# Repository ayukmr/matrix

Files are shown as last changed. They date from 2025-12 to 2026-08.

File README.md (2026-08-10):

# matrix



Charlieplexed LED matrix controlled by an ESP32-C6-MINI-1U.

## Schematic



## PCB



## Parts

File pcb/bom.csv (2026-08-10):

Reference | Qty | Value | Footprint | Datasheet | LCSC Part # | Link
C1,C2 | 2 | 2.2 µF | Capacitor_SMD:C_0603_1608Metric | ~ | C23630 | https://jlcpcb.com/partdetail/24366-CL10A225KO8NNNC/C23630
C3 | 1 | 1 µF | Capacitor_SMD:C_0603_1608Metric | ~ | C15849 | https://jlcpcb.com/partdetail/16531-CL10A105KB8NNNC/C15849
C4 | 1 | 22 µF | Capacitor_SMD:C_0603_1608Metric | ~ | C59461 | https://jlcpcb.com/partdetail/60514-CL10A226MQ8NRNC/C59461
C5 | 1 | 0.1 µF | Capacitor_SMD:C_0603_1608Metric | ~ | C14663 | https://jlcpcb.com/partdetail/YAGEO-CC0603KRX7R9BB104/C14663
D1,D2,D3,D4,D5,D6,D7,D8,D9,D10,D11,D12,D13,D14,D15,D16,D17,D18,D19,D20,D21,D22,D23,D24,D25,D26,D27,D28,D29,D30,D31,D32 | 32 | LED_Small | LED_SMD:LED_0603_1608Metric | ~ | C2286 | https://jlcpcb.com/partdetail/Hubei_KENTOElec-KT0603R/C2286
J1 | 1 | Conn_01x02 | Connector_JST:JST_PH_B2B-PH-SM4-TB_1x02-1MP_P2.00mm_Vertical | ~ | C160352 | https://jlcpcb.com/partdetail/JST-B2B_PH_SM4_TB_LF_SN/C160352
J2 | 1 | USB_C_Receptacle_USB2.0_14P | Connector_USB:USB_C_Receptacle_HRO_TYPE-C-31-M-12 | https://www.usb.org/sites/default/files/documents/usb_type-c.zip | C165948 | https://jlcpcb.com/partdetail/Korean_HropartsElec-TYPE_C_31_M12/C165948
R1,R2 | 2 | 5.1k Ω | Resistor_SMD:R_0603_1608Metric | ~ | C23186 | https://jlcpcb.com/partdetail/23913-0603WAF5101T5E/C23186
R3,R4 | 2 | 10k Ω | Resistor_SMD:R_0603_1608Metric | ~ | C25804 | https://jlcpcb.com/partdetail/26547-0603WAF1002T5E/C25804
R5,R6,R7,R8,R9,R10,R13,R14 | 8 | 470 Ω | Resistor_SMD:R_0603_1608Metric | ~ | C23179 | https://jlcpcb.com/partdetail/23906-0603WAF4700T5E/C23179
R11,R12 | 2 | 22 Ω | Resistor_SMD:R_0603_1608Metric | ~ | C23345 | https://jlcpcb.com/partdetail/24078-0603WAF220JT5E/C23345
SW1,SW2,SW3,SW4 | 4 | SW_Push | Button_Switch_SMD:SW_SPST_PTS810 | ~ | C720477 | https://jlcpcb.com/partdetail/XUNPU-TS_1088AR02016/C720477
U1 | 1 | ESP32-C6-MINI-1U | RF_Module:ESP32-C6-MINI-1U | https://www.espressif.com/sites/default/files/documentation/esp32-c6-mini-1_datasheet_en.pdf | C20627095 | https://jlcpcb.com/partdetail/22039339-ESP32_C6_MINI_1UH4/C20627095
U2 | 1 | XC6206PxxxMR | Package_TO_SOT_SMD:SOT-23-3 | https://www.torexsemi.com/file/xc6206/XC6206.pdf | C5446 | https://jlcpcb.com/partdetail/TorexSemicon-XC6206P332MRG/C5446

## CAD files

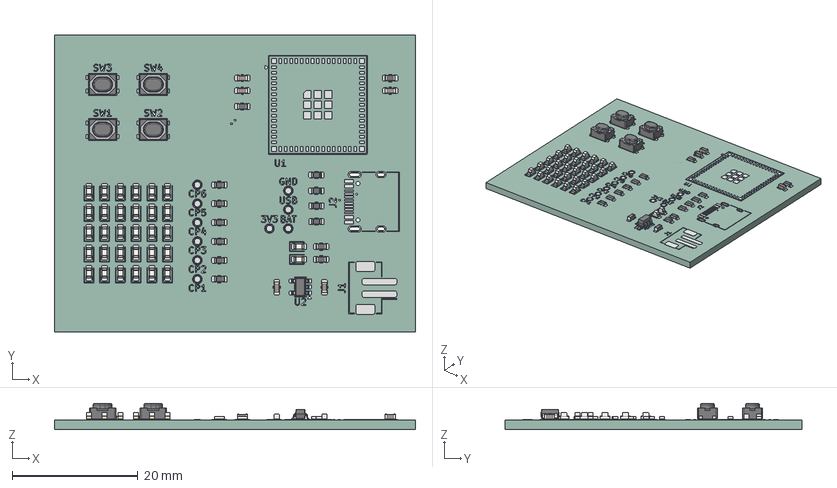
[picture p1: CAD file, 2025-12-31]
pcb/matrix.step
57.4 x 47.1 x 4.13 mm
C_0603_1608Metric x 5
R_0603_1608Metric x 14
SOT-23-5
SW_SPST_PTS810 x 4
LED_0603_1608Metric x 32
matrix_pad
matrix_silkscreen
matrix_PCB

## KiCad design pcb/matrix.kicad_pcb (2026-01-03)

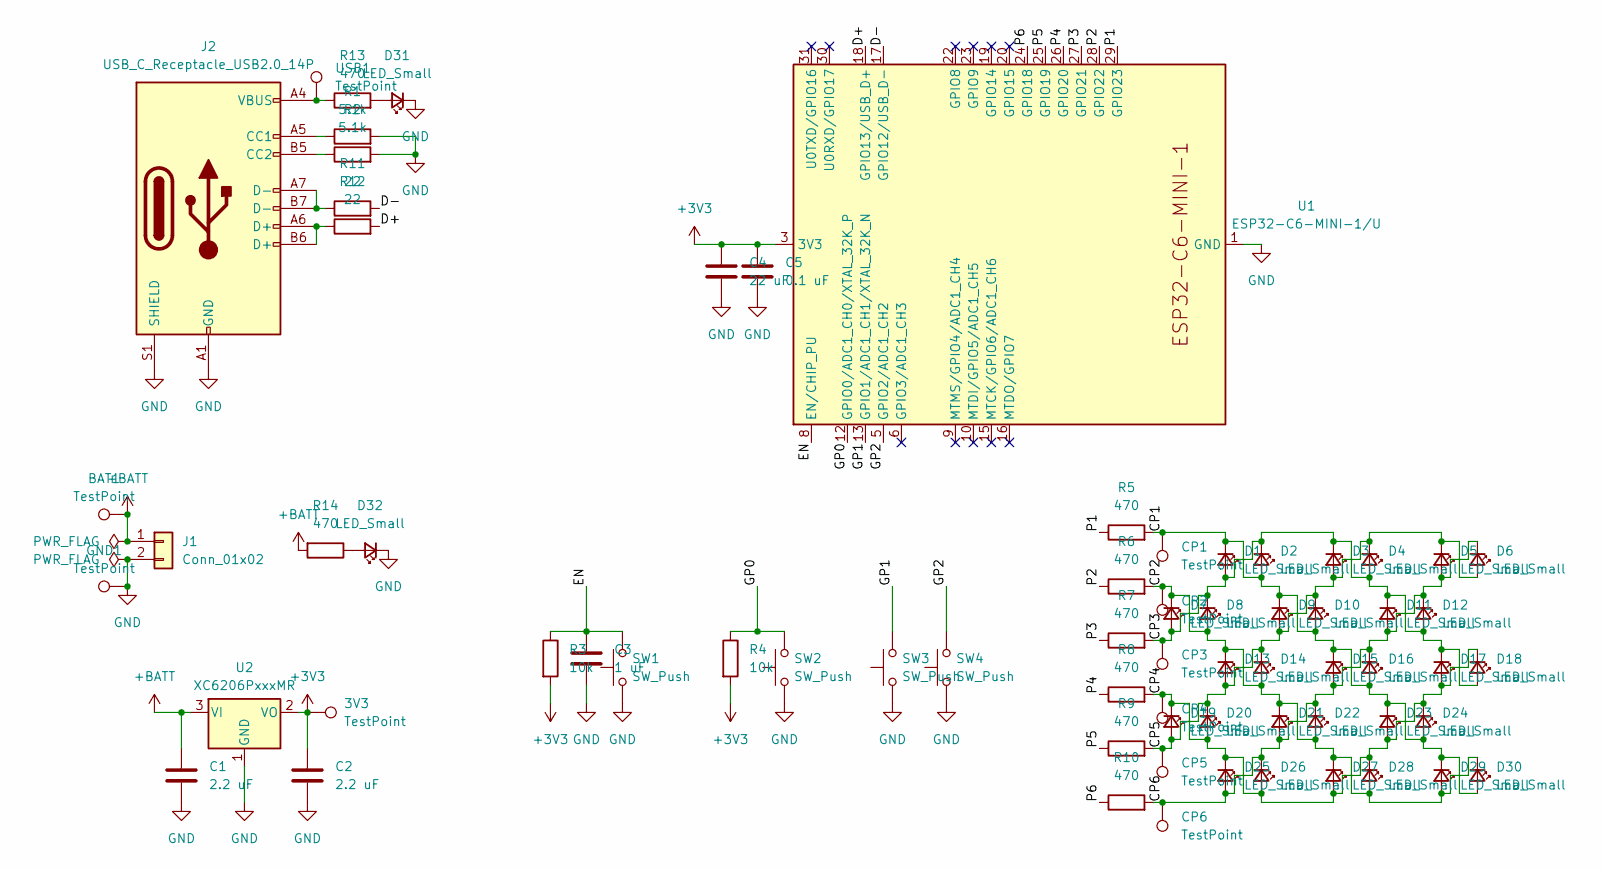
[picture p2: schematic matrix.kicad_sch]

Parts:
3V3: TestPoint; TestPoint_Pad_D1.0mm
BAT1: TestPoint; TestPoint_Pad_D1.0mm
C1, C2: 2.2 uF; C_0603_1608Metric
C3: 1 uF; C_0603_1608Metric
C4: 22 uF; C_0603_1608Metric
C5: 0.1 uF; C_0603_1608Metric
CP1, CP2, CP3, CP4, CP5, CP6: TestPoint; TestPoint_Pad_D1.0mm
D1, D2, D3, D4, D5, D6, D7, D8, D9, D10, D11, D12, D13, D14, D15, D16, D17, D18, D19, D20, D21, D22, D23, D24, D25, D26, D27, D28, D29, D30, D31, D32: LED_Small; LED_0603_1608Metric
GND1: TestPoint; TestPoint_Pad_D1.0mm
J1: Conn_01x02; JST_PH_B2B-PH-SM4-TB_1x02-1MP_P2.00mm_Vertical
J2: USB_C_Receptacle_USB2.0_14P; USB_C_Receptacle_HRO_TYPE-C-31-M-12
R1, R2: 5.1k; R_0603_1608Metric
R3, R4: 10k; R_0603_1608Metric
R5, R6, R7, R8, R9, R10, R13, R14: 470; R_0603_1608Metric
R11, R12: 22; R_0603_1608Metric
SW1, SW2, SW3, SW4: SW_Push; SW_SPST_TS-1088-xR020
U1: ESP32-C6-MINI-1/U; ESP32-C6-MINI-1U
U2: XC6206PxxxMR; SOT-23-3
USB1: TestPoint; TestPoint_Pad_D1.0mm

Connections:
+3V3: 3V3.1, C2.1, C4.1, C5.1, R3.2, R4.2, U1.3 (3V3), U2.2 (VO)
+BATT: BAT1.1, C1.1, J1.1, R14.2, U2.3 (VI); also elsewhere on the board
/CP1: CP1.1, D1.1 (K), D2.2 (A), D9.1 (K), D10.2 (A), D15.1 (K), D16.2 (A), D23.1 (K), D24.2 (A), D29.1 (K), D30.2 (A), R5.2
/CP2: CP2.1, D7.1 (K), D8.2 (A), D13.1 (K), D14.2 (A), D21.1 (K), D22.2 (A), D27.1 (K), D28.2 (A), D29.2 (A), D30.1 (K), R6.2
/CP3: CP3.1, D1.2 (A), D2.1 (K), D3.1 (K), D4.2 (A), D7.2 (A), D8.1 (K), D11.1 (K), D12.2 (A), D17.1 (K), D18.2 (A), R7.2
/CP4: CP4.1, D17.2 (A), D18.1 (K), D19.1 (K), D20.2 (A), D23.2 (A), D24.1 (K), D25.1 (K), D26.2 (A), D27.2 (A), D28.1 (K), R8.2
/CP5: CP5.1, D3.2 (A), D4.1 (K), D5.1 (K), D6.2 (A), D9.2 (A), D10.1 (K), D13.2 (A), D14.1 (K), D19.2 (A), D20.1 (K), R9.2
/CP6: CP6.1, D5.2 (A), D6.1 (K), D11.2 (A), D12.1 (K), D15.2 (A), D16.1 (K), D21.2 (A), D22.1 (K), D25.2 (A), D26.1 (K), R10.2
/D+: R12.2, U1.18 (GPIO13/USB_D+)
/D-: R11.2, U1.17 (GPIO12/USB_D-)
/EN: C3.1, R3.1, SW1.2, U1.8 (EN/CHIP_PU)
/GP0: R4.1, SW2.2, U1.12 (GPIO0/ADC1_CH0/XTAL_32K_P)
/GP1: SW3.2, U1.13 (GPIO1/ADC1_CH1/XTAL_32K_N)
/GP2: SW4.2, U1.5 (GPIO2/ADC1_CH2)
/P1: R5.1, U1.29 (GPIO23)
/P2: R6.1, U1.28 (GPIO22)
/P3: R7.1, U1.27 (GPIO21)
/P4: R8.1, U1.26 (GPIO20)
/P5: R9.1, U1.25 (GPIO19)
/P6: R10.1, U1.24 (GPIO18)
GND: C1.2, C2.2, C3.2, C4.2, C5.2, D31.1 (K), D32.1 (K), GND1.1, J1.2, J2.A1 (GND), J2.A12 (GND), J2.B1 (GND), J2.B12 (GND), J2.S1 (SHIELD), R1.2, R2.2, SW1.1, SW2.1, SW3.1, SW4.1, U1.1 (GND), U1.2 (GND), U1.11 (GND), U1.14 (GND), U1.36 (GND), U1.37 (GND), U1.38 (GND), U1.39 (GND), U1.40 (GND), U1.41 (GND), U1.42 (GND), U1.43 (GND), U1.44 (GND), U1.45 (GND), U1.46 (GND), U1.47 (GND), U1.48 (GND), U1.49 (GND), U1.50 (GND), U1.51 (GND), U1.52 (GND), U1.53 (GND), U2.1 (GND); also elsewhere on the board
unnamed: D31.2 (A), R13.2
unnamed: D32.2 (A), R14.1
unnamed: J2.A5 (CC1), R1.1
unnamed: J2.B5 (CC2), R2.1
unnamed: J2.A6 (D+), J2.B6 (D+), R12.1
unnamed: J2.A7 (D-), J2.B7 (D-), R11.1
unnamed 27: J2.A4 (VBUS), J2.A9 (VBUS), J2.B4 (VBUS), J2.B9 (VBUS), R13.1, USB1.1; also elsewhere on the board

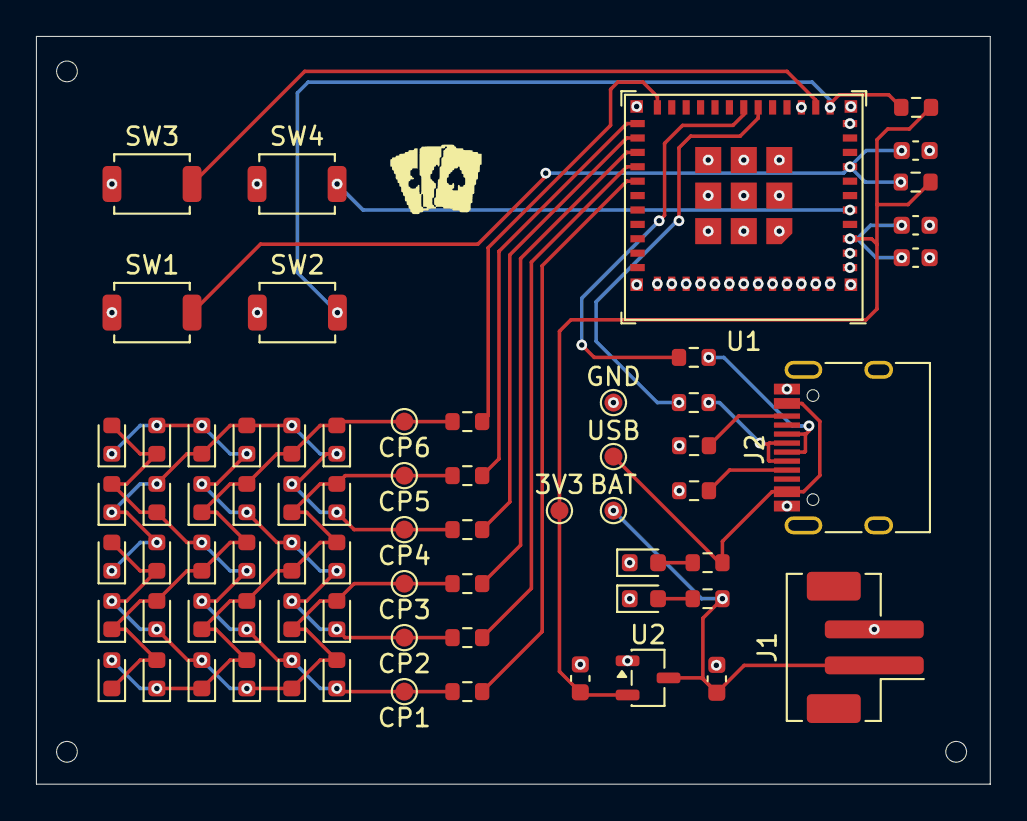
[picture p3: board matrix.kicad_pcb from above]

Board: 2 copper layers, 53.0 x 41.5 mm, 69 parts (0 on the bottom side), 28 nets.

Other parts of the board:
BAT: TestPoint; TestPoint_Pad_D1.0mm
GND: TestPoint; TestPoint_Pad_D1.0mm
USB: TestPoint; TestPoint_Pad_D1.0mm

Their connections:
+BATT: BAT.1; also elsewhere on the board
GND: GND.1; also elsewhere on the board
unnamed 27: USB.1; also elsewhere on the board

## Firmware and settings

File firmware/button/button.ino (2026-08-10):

#include <array>
#include <utility>
#include <algorithm>

int button1 = 1;
int button2 = 2;

std::array<int, 6> pins = {18, 19, 20, 21, 22, 23};

void setup() {
    for (int pin : pins) {
        pinMode(pin, INPUT);
    }

    pinMode(button1, INPUT_PULLUP);
    pinMode(button2, INPUT_PULLUP);
}

void loop() {
    bool b1 = digitalRead(button1) == LOW;
    bool b2 = digitalRead(button2) == LOW;

    if (b1) {
        pinMode(pins[5], OUTPUT);
        pinMode(pins[4], OUTPUT);

        digitalWrite(pins[5], HIGH);
        digitalWrite(pins[4], LOW);

        delayMicroseconds(500);
    }

    if (b2) {
        pinMode(pins[5], OUTPUT);
        pinMode(pins[4], OUTPUT);

        digitalWrite(pins[5], LOW);
        digitalWrite(pins[4], HIGH);

        delayMicroseconds(500);
    }

    pinMode(pins[5], INPUT);
    pinMode(pins[4], INPUT);
}

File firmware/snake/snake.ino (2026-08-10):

#include <array>
#include <vector>
#include <utility>
#include <algorithm>

int button1 = 1;
int button2 = 2;

int score = 3;

std::array<int, 6> pins = {18, 19, 20, 21, 22, 23};

std::array<std::array<std::pair<int, int>, 3>, 5> pairs = {{
    {{{2, 0}, {4, 2}, {5, 4}}},
    {{{2, 1}, {4, 0}, {5, 2}}},
    {{{4, 1}, {5, 0}, {3, 2}}},
    {{{4, 3}, {5, 1}, {3, 0}}},
    {{{5, 3}, {3, 1}, {1, 0}}}
}};

std::array<std::array<bool, 6>, 5> leds = {};

std::vector<std::pair<int, int>> snake = {{1, 1}};
std::pair<int, int> dir = {-1, 0};

std::pair<int, int> fruit = {4, 3};

void setup() {
    for (int pin : pins) {
        pinMode(pin, INPUT);
    }

    pinMode(button1, INPUT_PULLUP);
    pinMode(button2, INPUT_PULLUP);
}

void loop() {
    updateSnake();
    updateDir();
    updateMat();
    plex();
}

unsigned long last = 0;

void updateSnake() {
    unsigned long now = millis();

    if (now - last >= 500) {
        last = now;

        std::pair head = snake.front();

        std::pair next = {
            (head.first + dir.first + 6) % 6,
            (head.second + dir.second + 5) % 5
        };
        snake.insert(snake.begin(), next);

        if (snake.size() > score) {
            snake.pop_back();
        }
    }
}

bool b1Fired = false;
bool b2Fired = false;

void updateDir() {
    if (digitalRead(button1) == LOW) {
        if (!b1Fired) {
            dir = {dir.second, -dir.first};
            b1Fired = true;
        }
    } else {
        b1Fired = false;
    }

    if (digitalRead(button2) == LOW) {
        if (!b2Fired) {
            dir = {-dir.second, dir.first};
            b2Fired = true;
        }
    } else {
        b2Fired = false;
    }
}

void updateMat() {
    for (auto& row : leds) {
        row.fill(false);
    }

    for (auto limb : snake) {
        leds[limb.second][limb.first] = true;
    }
}

void plex() {
    for (int y = 0; y < 5; y++) {
        for (int x = 0; x < 3; x++) {
            auto [lo, hi] = pairs[y][x];

            for (int i = 0; i < 2; i++) {
                bool on = leds[y][5 - (x * 2 + i)];

                for (int pin : pins) {
                    pinMode(pin, INPUT);
                }

                if (on) {
                    pinMode(pins[lo], OUTPUT);
                    pinMode(pins[hi], OUTPUT);

                    digitalWrite(pins[lo], LOW);
                    digitalWrite(pins[hi], HIGH);
                }

                delayMicroseconds(500);
                std::swap(lo, hi);
            }
        }
    }

    for (int pin : pins) {
        pinMode(pin, INPUT);
    }
}

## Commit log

2025-12-30 Initialize repo
    [bom.csv, matrix.kicad_pcb, matrix.kicad_sch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]
2025-12-31 Refill zone
    [matrix.kicad_pcb]
2025-12-31 Update silkscreen
    [matrix.kicad_pcb, matrix.kicad_sch]
2025-12-31 Fix incorrect voltage
    [matrix.kicad_pcb, matrix.kicad_sch, matrix.step]
2025-12-31 Update parts
    [bom.csv, matrix.kicad_pcb, matrix.kicad_sch]
2025-12-31 Update README BOM
2026-01-02 Replace components
    [bom.csv, matrix.kicad_pcb, matrix.kicad_sch]
2026-01-03 Update to C6-MINI
    [bom.csv, matrix.kicad_pcb, matrix.kicad_sch]
2026-01-03 Organize schematic
    [matrix.kicad_sch]
2026-01-14 Update BOM
    [bom.csv]
2026-02-06 Remove BOM
